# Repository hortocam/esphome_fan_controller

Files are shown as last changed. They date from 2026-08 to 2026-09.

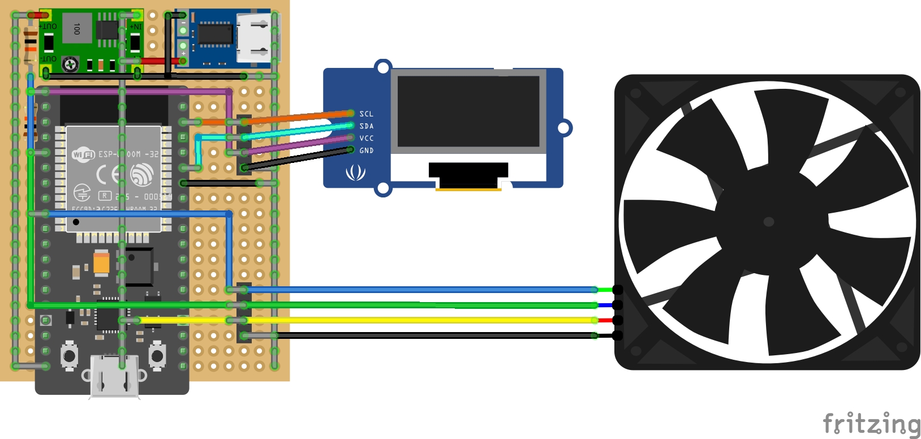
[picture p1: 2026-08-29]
docs/perfboard-layout_bb.jpg

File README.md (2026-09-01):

# UCG-Max Fan Controller

ESPHome-based, MQTT-driven PWM fan controller for a UniFi **UCG-Max** router, with
an SSD1306 OLED showing router temp, fan duty, and RPM.

The firmware itself is **agnostic about the temperature source**. It only
subscribes to MQTT topics; a small Prometheus→MQTT bridge publishes the current
router temperature. Point the bridge at any metric / router / data source
without ever touching the device firmware — swap the bridge, not the board.

## Why this exists

The UCG-Max sits on a custom stand with a Noctua 4-wire 12 V fan driven by a
temp-probe PWM controller. That controller's surface probe reads **~17–18 °C
below** the router's actual SoC/SNMP temperature, so it lags badly on load
spikes (a 3 °C jump while the fan is still spinning at idle speed). This project
replaces the probe controller with an ESP32 that reads the *real* temperature
and drives the fan from a proper curve.

## Architecture

```
+----------------+   SNMP / PromQL   +----------------------+
|  UCG-Max       |  ->  Prometheus  | prometheus_to_mqtt.py |
|  (SNMP exporter)                |  (bridge, e.g. on a CT) |
+----------------+                   +----------+-----------+
                                                | MQTT publish
                                                | homelab/ucgmax/temperature
                                                v
                                     +----------------------+
                                     |  ESP32 (ESPHome)     |
                                     |  - subscribes MQTT  |
                                     |  - fan curve + fail-|
                                     |    safe             |
                                     |  - drives 4-wire PWM|
                                     |  - OLED display     |
                                     +----------------------+
```

**The one line that ties a specific source to the fan is the MQTT topic the
bridge publishes to.** Point the bridge at any metric (SNMP OID, PromQL query,
a different router, a weather API...) and the ESP32 behaves identically.

## Repository layout

```
esphome/
  fan_controller.yaml   # ESPHome device config (pins, curve, MQTT, OLED)
  secrets.yaml          # LOCAL-ONLY, gitignored - fill in, never commit
scripts/
  prometheus_to_mqtt.py # Prometheus -> MQTT bridge (the only SNMP/PromQL spot)
firmware/               # (future) raw PlatformIO fallback if ESPHome is dropped
README.md
LICENSE                 # MIT
```

## MQTT topics

| Topic | Direction | Payload | Purpose |
|---|---|---|---|
| `homelab/ucgmax/temperature` | bridge → ESP32 | float, °C | router temp driving the curve |
| `homelab/ucgmax/#` | bridge → ESP32 | any | keeps failsafe armed (heartbeat) |

The ESP32 also exposes ESPHome-native sensors (`Fan Duty`, `Fan RPM`, `Router
Temperature`, `Status`) over its own MQTT discovery topics, so it can appear as
a normal device in Home Assistant if you want.

## Fan curve

Tuned to **SNMP/tsens** temperatures (the real SoC temp):

| Temp (°C) | Duty |
|---|---|
| < 45 | 20 % |
| 45–65 | linear 20 → 100 % |
| > 65 | 100 % |

## Failsafe

If no MQTT message arrives for `stale_timeout` (default 60 s) — bridge down,
WiFi lost, topic renamed — the fan drives to `fail_duty` (default 50 %) so the
router stays cool rather than going silent. Two layers are intended: this
software failsafe **plus** a 10 kΩ pull-up on the PWM line to 5 V that drives
the fan to 100 % if the ESP32 dies entirely.

## Wiring (pending — verify against your board)

Pin assignments in `fan_controller.yaml` are **placeholders** until the board
silkscreen is read. 4-wire fan header:

| Fan wire | Colour (typical) | ESP32 GPIO |
|---|---|---|
| Ground | black | GND |
| +12 V | yellow | 12 V (level-shifted / via fan supply) |
| Tach | green | GPIO_NC (pulse_counter) |
| PWM | blue | GPIO_NC (ledc 25 kHz) |

> **12 V warning:** do NOT feed 12 V into a bare ESP32 GPIO. Either drive the
> fan's PWM input directly (it accepts a 3.3 V signal on many Noctua fans) or
> use a level shifter (e.g. BSS138/2N7000) if the fan requires a 5 V PWM.

OLED (SSD1306 128×64) on I2C (SDA/SCL), address 0x3C.

## Setup

```bash
# 1. Install ESPHome (any host - Mac or a Python venv on the Pi)
pip install esphome   # or: uv tool install esphome

# 2. Set your secrets
cp esphome/secrets.yaml.example esphome/secrets.yaml
$EDITOR esphome/secrets.yaml      # wifi, mqtt broker/user/pass

# 3. Set the real pin numbers in esphome/fan_controller.yaml

# 4. Validate + build + flash
esphome compile esphome/fan_controller.yaml
esphome run esphome/fan_controller.yaml   # or upload via serial / OTA
```

## The bridge

`scripts/prometheus_to_mqtt.py` polls a Prometheus query (default
`lmTempSensorsValue{instance="172.16.10.1"}`, the SNMP-exposed router temps) and
publishes the max of the two sensors (millidegrees ÷ 1000 → °C) to MQTT. Run it
as a service or cron. Edit the PromQL in the `--query` flag to change the source
without touching firmware. See the script header for full options.

## Status

- [x] Repo scaffold, ESPHome layout, bridge
- [x] `esphome config` validated — EXCEPT the placeholder GPIO pins (see below)
- [x] Verify wiring / set real pins (tach, PWM, OLED I2C)
- [x] Full build + first flash + serial boot log
- [x] OLED layout pass on real hardware
- [x] Failsafe E2E (kill MQTT, watch fan)
- [ ] Enclosure + install

> **Pin status (intentional):** `GPIO_NC` placeholders are left in for the tach
> pulse_counter, the ledc fan PWM, and the OLED I2C pins. `esphome config`
> will NOT pass clean until these are set to real GPIOs (pulse_counter requires
> an integer pin). This is deliberate — wrong pins are the #1 cause of a dead
> board, so pins are set from the actual board silkscreen, not guessed.
>
> **ESPHome version note:** config targets ESPHome ≥2026.x. The legacy
> `platform: ESP32` key inside the `esphome:` block was removed in modern
> releases — use the `esp32:` component with `framework: arduino` instead.

MIT Licensed — see `LICENSE`.

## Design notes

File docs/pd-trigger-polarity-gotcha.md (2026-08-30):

# USB-C PD Trigger — Fritzing Part Polarity Gotcha

> Logged 2026-08-30 after a failed solder attempt. **The Fritzing part's pinout did NOT
> match the physical module, and the netlist could not catch it.**

## What happened

The fan-controller perfboard used a common Fritzing "usbc to 12V module" part. When
soldering, the **polarity of that part was backwards from the physical USB-C PD trigger
module** — the Fritzing part showed +12V where the real board had GND (and vice-versa).
Reconciling that on the fly at the board produced a short.

## Why the netlist verification didn't catch it

The `fritzing-netlist-verification` workflow parses the exported netlist and maps Fritzing's
positional pins to GPIOs. But the netlist only knows **what Fritzing thinks the pins are**.
If the part's footprint itself is wrong vs the physical module, the netlist verifies
"correct" — because it matches the (wrong) part. This is the one class of error netlist
verification cannot catch.

## Lesson

For **power parts** (PD trigger, buck converter, regulators), always cross-check the
physical module's **silkscreen / datasheet pinout** against the Fritzing part's pin labels
BEFORE trusting the netlist. A reversed polarity on a power rail is a short waiting to
happen.

## Action

- Cameron is searching for a **better / correct Fritzing part** for the USB-C PD trigger
  (one whose pinout matches the physical module).
- When a replacement part is found, re-verify the layout with the netlist workflow, and
  confirm the physical module's +12V / GND / CC pins against the part before soldering.

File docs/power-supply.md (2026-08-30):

# Power Supply Design — USB-C PD to Fan + Controller

A single surplus USB-C PD supply powers both the fan (12 V) and the controller
board (5 V). The key component is a **USB-C PD trigger module** (a PD *sink*)
that negotiates the 12 V PDO from the PSU, plus a buck converter to step that
down to 5 V for the NodeMCU.

## Block diagram

```
USB-C PD supply  (surplus, 5/9/12/20 V PDOs)
        │
        ▼
USB-C PD trigger module  (CH224K, strapped for 12 V)
        │   └── 12 V rail  ──┬──► Fan  (VCC +12 V, GND)
        │                    └──► Buck 12 V→5 V  (MP1584)  ──► NodeMCU 5V/VIN
```

- **12 V rail → fan directly.** The fan's PWM (GPIO25) and tach (GPIO34) logic
  lines are referenced to this rail's ground, so they stay under the 3.3 V logic
  domain of the ESP as long as everything shares a common ground.
- **Buck → NodeMCU 5V/VIN** (the on-board 3.3 V regulator then feeds the ESP +
  OLED). The buck only carries the board, not the fan, so it stays small.

## Parts (all ~$2–4 on AliExpress/Amazon)

| Component | Part | Notes |
|---|---|---|
| PD trigger | **CH224K** breakout | Negotiates a requested PDO. Voltage-select straps (dip / solder) → set to 12 V. |
| Buck 12 V→5 V | **MP1587 / MP1584** or fixed-5 V mini buck | ~500 mA enough for ESP32 + OLED. Fixed 5 V simpler; adjustable trim to 5 V also fine. |

## Wiring / pinout

- **Common ground everywhere** — 12 V rail GND, buck GND, and NodeMCU GND all
  tied together. PWM/tach are referenced to the fan's ground, so one 0 V
  reference is mandatory.
- **NodeMCU 5V (VIN)** ← buck 5 V. No USB needed in the final mount.
- **PWM GPIO25 → fan PWM** (3.3 V logic, common-ground). Same as bench.
- **TACH GPIO34 ← fan tach**, with **10 kΩ pull-up to 3.3 V** (the ESP's 3.3 V,
  NOT the 12 V rail).

## Pinout — CONFIRMED against Fritzing netlist (2026-08-29)

The perfboard layout (`perfboard-layout.fzz`) was verified by parsing the exported
netlist XML against the firmware pin map. These positions are the physical NodeMCU-32S
pins (Fritzing 38-pin part):

| Signal | ESP32 GPIO | Fritzing Pin | Netlist status |
|---|---|---|---|
| OLED SDA | GPIO21 | Pin 33 | ✅ verified |
| OLED SCL | GPIO22 | Pin 36 | ✅ verified |
| Fan PWM  | GPIO25 | Pin 9  | ✅ verified |
| Fan TACH | GPIO34 | Pin 5  | ✅ verified |
| OLED VCC | 3.3 V | Pin 1  | ✅ verified |
| ESP32 5V | V5 | Pin 19 | ✅ verified |
| GND (common) | — | Pins 14/32/38 | ✅ verified |

Pull-ups confirmed: **R2 (10 kΩ)**: PWM/GPIO25 → 5 V rail (failsafe fail-open).
**R3 (10 kΩ)**: TACH/GPIO34 → 3.3 V rail.

> **Fritzing gotcha:** the fan 4-wire breakout's **pins in the part are NOT in physical
> order** — that earlier swapped PWM/TACH at the ESP32 (both were wired to the opposite
> GPIO). Fixed at the fan component. Verify with the netlist, never the rendered image.

## PD supply requirements

- The surplus PSU must actually **advertise a 12 V PDO**. The list
  (5/9/12/20 V) is the standard PD set, so a 12 V PDO should be present — check
  the label for "12 V" in the output/POWER DELIVERY table.
- Use a **USB-C cable with the CC lines** (not a charge-only cable) so the
  CH224K can negotiate. A PD/e-marked cable is ideal.

## Failsafe (two layers)

1. **Software** — if MQTT data goes stale for `stale_timeout` (default 60 s),
   the ESP drives the fan to `fail_duty` (default 50 %). Covers bridge down /
   WiFi lost / topic renamed.
2. **Hardware (fail-open) — worth wiring now that we have a clean 5 V rail.**
   A **10 kΩ pull-up from the PWM line (GPIO25) to 5 V** holds the fan at
   ~100 % if the ESP32 dies or its GPIO floats, so the router stays cool even
   with a dead controller. Without this, a dead ESP32 leaves the fan stuck at
   whatever the last state was.

  **Pitfall:** this pull-up must be to the **5 V rail, NOT 3.3 V** and NOT to
  the 12 V rail — GPIO25 is a 3.3 V-tolerant pin; pulling it to 12 V would
  damage the ESP32.

## Bench verification checklist (before mounting)

- [ ] PD trigger outputs ~12 V (meter the 12 V rail to common GND).
- [ ] Buck outputs ~5 V (meter to common GND).
- [ ] NodeMCU boots from the buck 5 V (no USB).
- [ ] Fan spins at ~100 % when PWM pulled high (failsafe test: pull GPIO25 to 5 V).
- [ ] Tach reads a sane RPM at 100 % duty (~17 k RPM for the 17k fan).
- [ ] OLED on and readable.

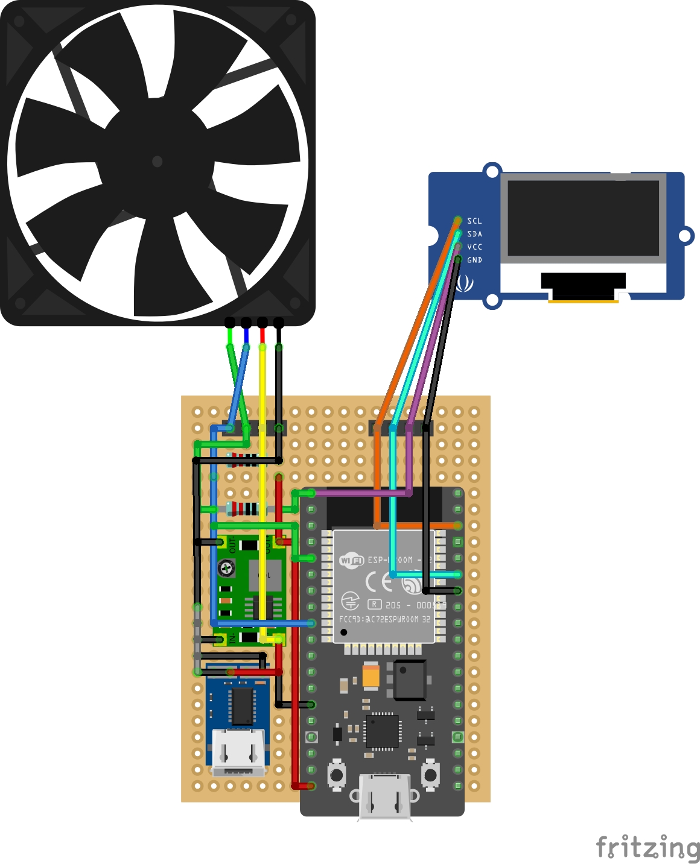
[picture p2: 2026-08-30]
docs/perfboard-layout-v2/perfboard-layout_bb.jpg

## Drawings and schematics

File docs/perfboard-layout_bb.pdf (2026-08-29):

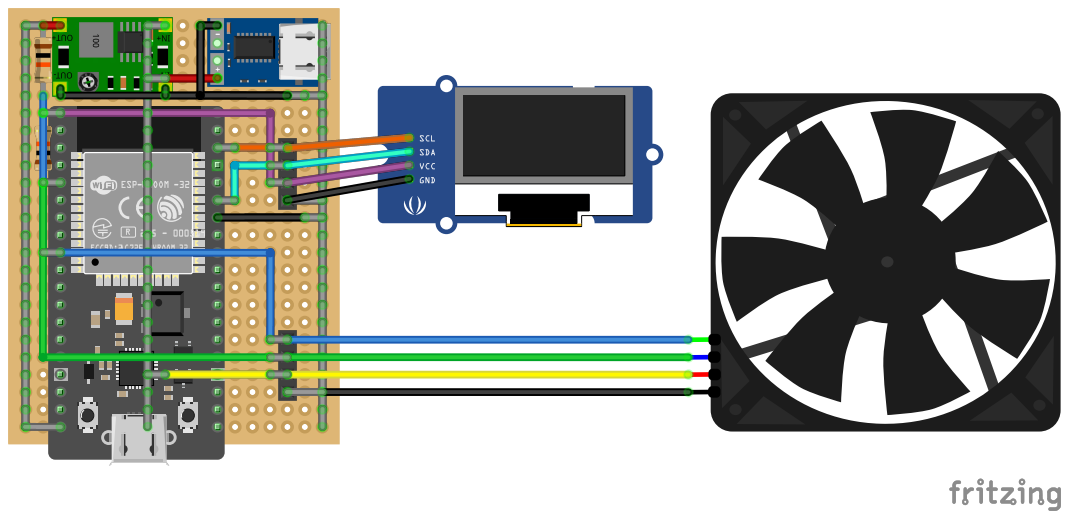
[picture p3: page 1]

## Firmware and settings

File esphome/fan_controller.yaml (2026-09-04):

# UCG-Max Fan Controller — ESPHome config
#
# ESPHome-driven 4-wire PWM fan for the UniFi UCG-Max.
#
# DESIGN GOAL: the firmware is agnostic about WHERE the temperature comes from.
# It subscribes to MQTT topics only. The Prometheus -> MQTT bridge
# (scripts/prometheus_to_mqtt.py) is the ONE place an SNMP OID / PromQL query
# appears, so pointing this at a different metric, router, or data source never
# touches the device firmware. Swap the bridge, not the board.
#
# STATUS: PENDING — initial layout, NOT yet flashed. Pin assignments are
# PLACEHOLDERS (GPIO_NC). Read the board silkscreen / wiring table first (see
# the esp32-firmware skill) and set the real pins before building.

substitutions:
  device_name: fan-controller
  # Duty (0.0-1.0) driven when MQTT data is stale or was never received.
  fail_duty: "0.5"
  # Seconds of silence before the failsafe engages.
  stale_timeout: "60"

esphome:
  name: ${device_name}
  friendly_name: UCG-Max Fan Controller

# Reports the reason for the last boot (brownout, watchdog, panic, ...).
# The debug component itself only takes update_interval; the actual
# reset_reason text sensor is a separate debug-platform text_sensor (see
# below) — it answers "why did it reboot?" after the fact, since runtime
# logs are lost on a hard reset.
debug:
  update_interval: 60s

logger:
  level: DEBUG

ota:
  - platform: esphome
    password: !secret ota_password

api:
  encryption:
    key: !secret api_encryption_key

esp32:
  board: nodemcu-32s
  framework:
    type: arduino

# ############################### NETWORK #################################
wifi:
  ssid: !secret wifi_ssid
  password: !secret wifi_password
  # Static IP so monitoring/OTA is predictable. Uncomment + adjust.
  # manual_ip:
  #   static_ip: 172.16.20.9
  #   gateway: 172.16.20.1
  #   subnet: 255.255.255.0
  #   dns1: 172.16.10.18
  #   dns2: 8.8.8.8
  reboot_timeout: 0s

# ############################### MQTT ####################################
mqtt:
  broker: !secret mqtt_broker
  port: 1883
  username: !secret mqtt_username
  password: !secret mqtt_password
  discovery: true
  discovery_retain: true

# ############################ SENSORS ####################################
globals:
  - id: current_temp
    type: float
    restore_value: no
    initial_value: "0.0"
  - id: last_temp_seen
    type: unsigned long
    restore_value: no
    initial_value: "0"

sensor:
  - platform: template
    name: "Router Temperature"
    id: router_temp_sensor
    unit_of_measurement: "°C"
    accuracy_decimals: 1
    state_class: measurement

  - platform: template
    name: "Fan Duty"
    id: fan_duty_sensor
    unit_of_measurement: "%"
    accuracy_decimals: 0
    state_class: measurement

  - platform: pulse_counter
    name: "Fan RPM"
    id: fan_rpm
    pin: GPIO34         # << TACH - NodeMCU-32S. 10k pull-up to 3.3V required
    update_interval: 5s
    filters:
      - multiply: 0.5    # 2 pulses/rev; 100% = 3000 RPM (was 5.0 = 10x too high)

  # Subscribe to the router temp published by the Prometheus->MQTT bridge.
  # mqtt_subscribe is the reliable way to react to a topic (the top-level
  # mqtt: on_message: trigger was flaky and never fired on this device).
  - platform: mqtt_subscribe
    name: "Router Temp (MQTT)"
    id: mqtt_temp
    topic: homelab/ucgmax/temperature
    qos: 1
    on_value:
      - lambda: |-
          ESP_LOGD("fan", "MQTT temp received: %.1f", x);
          id(current_temp) = x;
          id(last_temp_seen) = millis();
          id(router_temp_sensor).publish_state(x);

# ############################ OUTPUT / FAN ##############################
output:
  - platform: ledc
    id: fan_pwm
    pin: GPIO25         # PWM (NodeMCU-32S). Noctua accepts 3.3V directly
    frequency: 25000 Hz  # 4-wire fan spec: 25 kHz PWM

fan:
  - platform: speed
    id: router_fan
    output: fan_pwm
    name: "Router Fan"
    speed_count: 100
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

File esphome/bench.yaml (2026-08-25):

# UCG-Max Fan Controller — BENCH TEST CONFIG (first flash, no MQTT)
#
# Purpose: prove the hardware on the bench BEFORE wiring up MQTT/Prometheus.
# No MQTT broker required. On boot it ramps the fan 0->100% in steps and reads
# the tach, so you can confirm in ~30s that:
#   1. WiFi connects (IoT VLAN)
#   2. The fan PWM drives the blade (it visibly spins)
#   3. The tach / RPM reads a real value (GPIO34 + 10k pull-up to 3.3V)
#   4. The OLED renders temp/duty/RPM (GPIO21/22)
#
# This is a throwaway test config - NOT the production one (fan_controller.yaml).
# Commit it alongside so future flashes can re-run the bench check.

substitutions:
  device_name: fan-controller-bench

esphome:
  name: ${device_name}
  friendly_name: UCG-Max Fan Controller (Bench)

esp32:
  board: nodemcu-32s
  framework:
    type: arduino

# Serial logging so `esphome run` / monitor shows the sweep, RPM, and I2C scan.
# INFO (not DEBUG): DEBUG floods the serial with raw SSD1306 framebuffer bytes.
logger:
  level: INFO
  baud_rate: 115200

wifi:
  ssid: !secret wifi_ssid
  password: !secret wifi_password
  reboot_timeout: 0s

# ---------- HARDWARE ----------
output:
  - platform: ledc
    id: fan_pwm
    pin: GPIO25
    frequency: 25000 Hz

fan:
  - platform: speed
    id: router_fan
    output: fan_pwm
    name: "Router Fan"
    speed_count: 100

sensor:
  - platform: pulse_counter
    name: "Fan RPM"
    id: fan_rpm
    pin: GPIO34
    update_interval: 2s
    filters:
      - multiply: 5.0    # 2s interval -> RPM; ~10x under-read with 0.5

text_sensor:
  - platform: template
    name: "Bench Status"
    id: bench_status
    lambda: |-
      return {"RUNNING"};

# ---------- 30s SPEED SWEEP ----------
# Ramp 0 -> 100% and back twice, 2s per step, so you can SEE the blade
# respond and the RPM climb.
interval:
  - interval: 2s
    then:
      - lambda: |-
          static int step = 0;
          float t = (step % 100) / 99.0f;                 // 0..1 over 100 steps
          float duty = (step / 100) % 2 ? (1.0f - t) : t; // triangle wave 0->1->0
          id(router_fan).make_call().set_state(true).set_speed((int)round(duty * 100)).perform();
          const char* label = duty < 0.01f ? "STOP" : duty < 0.34f ? "LOW " : duty < 0.67f ? "MID  " : "HIGH";
          id(bench_status).publish_state(label);
          step = (step + 1) % 200;

# ---------- OLED ----------
i2c:
  sda: GPIO21
  scl: GPIO22
  scan: true

display:
  - platform: ssd1306_i2c
    id: oled
    model: "SSD1306 128x64"
    address: 0x3C
    update_interval: 1s
    lambda: |-
      it.printf(0, 0, id(font_oled), "FAN  %3d %%", id(router_fan).speed);
      it.printf(0, 20, id(font_oled), "RPM  %5d", (int)round(id(fan_rpm).state));
      it.printf(0, 40, id(font_oled), "%s", id(bench_status).state.c_str());

font:
  - id: font_oled
    file: "gfonts://Roboto"
    size: 12

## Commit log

2026-08-24 Initial ESPHome fan controller layout
    - esphome/fan_controller.yaml: ESPHome config (PWM fan, SSD1306 OLED,
    MQTT-subscribed temperature, fan curve + software failsafe)
    - scripts/prometheus_to_mqtt.py: Prometheus->MQTT bridge (the only
    SNMP/PromQL location in the project - firmware is source-agnostic)
    - esphome/secrets.yaml.example: local-only secrets template (gitignored)
    - README: architecture, MQTT topics, wiring (pending), status
    Status: scaffold only. Pins are placeholders (GPIO_NC) pending board
    silkscreen. Not yet flashed.
    [fan_controller.yaml]
2026-08-24 Fix modern ESPHome platform declaration
    ESPHome 2026.x removed the legacy 'platform:' key from the esphome: block.
    Use the esp32: component with arduino framework instead. Validated against
    ESPHome 2026.8.1.
    [fan_controller.yaml]
2026-08-24 Document pin status + modern ESPHome requirement
2026-08-25 Set real pins: PWM GPIO25, TACH GPIO34, OLED I2C 21/22
    NodeMCU-32S. TACH (GPIO34) requires a 10k pull-up to 3.3V (fan's tach
    swings only ~1.1V on its own - too weak for the ESP32 high threshold).
    PWM (GPIO25) drives the Noctua directly at 3.3V. OLED on GPIO21/22.
    [fan_controller.yaml]
2026-08-25 Add bench.yaml - no-MQTT first-flash test
    Ramps fan 0->100% in a 30s triangle sweep on boot, reads tach RPM, drives
    OLED - proves PWM/tach/I2C on the bench before MQTT/Prometheus is wired.
    Throwaway test config; production stays in fan_controller.yaml.
2026-08-25 Fix SpeedFan member: use .speed not .speed_speed
    speed::SpeedFan exposes the target duty as .speed; .speed_speed does not exist and broke the C++ compile. Fixed in both bench.yaml and fan_controller.yaml.
    [fan_controller.yaml]
2026-08-25 Add logger to bench.yaml for serial capture
    First bench flash had no logger component, so esphome run's monitor exited
    with 'Logger is not configured!' and no sweep/RPM/I2C output could be seen.
2026-08-25 Fix SpeedFan truncation: set_speed(int) not .speed=float; INFO logger; bench OLED duty display
    SpeedFan::speed is an int 0-100; assigning a float duty in [0,1) truncated
    everything to 0% so the fan never spun. Use make_call().set_speed(int).
    Same bug in fan_controller.yaml (prod). Bench logger DEBUG flooded serial
    with raw SSD1306 framebuffer bytes - drop to INFO. Bench OLED shows
    speed directly (0-100), not *100.
    [fan_controller.yaml]
2026-08-25 Fix RPM tach scale: multiply 0.5 -> 5.0
    At 100% duty the fan reads ~1695 RPM but its true max is ~17k - the
    tach is under-reading by 10x. pulse_counter normalizes to per-minute;
    multiply 5.0 corrects the scale in both bench and production configs.
    [fan_controller.yaml]
2026-08-25 Add USB-C PD power-supply design doc
    CH224K PD trigger for the 12V fan rail + MP1584 buck to 5V for the NodeMCU.
    Covers wiring, parts, common-ground requirement, and the two-layer failsafe
    (software stale->50%, hardware 10k PWM pull-up to 5V fail-open).
2026-08-29 Created perfboard in Fritzing and related images.
    [perfboard-layout.fzz]
2026-08-29 Swapped RPM & PWM wires at the fan component. New netlist.
    [perfboard-layout.fzz]
2026-08-29 docs: confirm fan-controller pinout against Fritzing netlist (2026-08-29)
2026-08-30 fan controller board layout yaml
    [fan-controller-board.yaml]
2026-08-30 fix fritzing-stripboard yaml: add required meta.label field
    [fan-controller-board.yaml]
2026-08-30 version 2 of the perfboard
    [perfboard-layout.fzz]
2026-08-31 add logger: DEBUG to fan_controller.yaml (fix 'Logger is not configured')
    [fan_controller.yaml]
2026-08-31 fix RPM multiplier (0.5, 100%=3000rpm) and OLED line spacing (16px, no cutoff)
    [fan_controller.yaml]
2026-09-01 add debug log to MQTT temp on_message handler
    [fan_controller.yaml]
2026-09-01 switch MQTT temp handling to mqtt_subscribe sensor (top-level on_message never fired)
    [fan_controller.yaml]
2026-09-01 fix mqtt_subscribe on_value lambda: x is already a float
    [fan_controller.yaml]
2026-09-01 mark fan controller working: wiring, flash, OLED, failsafe all verified
2026-09-01 retune fan curve for NF-PPC3000: floor 45%, ~55% duty at 48C (~1650rpm) matching old controller
    [fan_controller.yaml]
2026-09-01 add OTA (esphome) + API encryption key for future OTA flashing
    [fan_controller.yaml]
2026-09-04 fix status sensor 60s BOOT clobber + add debug reset_reason sensor
    - template text_sensor: update_interval: never so its lambda can't
    re-evaluate every 60s and clobber ONLINE/STALE published by the 5s
    fan-curve interval (caused intermittent 'BOOT' flashes on OLED/HA)
    - add debug component with reset_reason: true to log boot cause
    (brownout/watchdog/panic) after real resets
    [fan_controller.yaml]
2026-09-04 fix debug schema: reset_reason is a debug text_sensor platform, not a debug component option
    [fan_controller.yaml]
